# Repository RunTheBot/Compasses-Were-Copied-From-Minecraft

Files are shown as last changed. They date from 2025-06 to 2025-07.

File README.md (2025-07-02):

# Compass from Minecraft
A real compass for Minecraft, which points north in the real world.

## Features
- Points to the North in the real world.
- Looks like a minecraft compass.
- Can be used in any IRL version

## Images


<sub><sup> Got lazy with textures </sup></sub>


<sub><sup> The exploded view is upsidedown, thats why you dont see bolts in the render.</sup></sub>



## BOM

| Name | Quantity | Single Unit Price | Total Price | URL/LCSC | FALSE | Vendor (LCSC unless otheriwse indicated) | |
|---|---|---|---|---|---|---|---|
| Electronics | | | | | FALSE | | |
| C5 0603 0.1uF | 40 | | 0.45 | C49678 | FALSE | With My other two projects | |
| SK6812MINI | 40 | | $2.96 | C5149201 | FALSE | | |
| SEEED XIAO 2040 | 1 | | $3.99 | https://www.seeedstudio.com/XIAO-RP2040-v1-0-p-5026.html | FALSE | | |
| PCB - JLC | | | $9.00 | | FALSE | | |
| LCSC - Shipping and handling | | | $17.38 | | FALSE | | |
| magnometer | | | $2.07 | C2654971 | FALSE | | |
| JLC - Shipping | | | $10.38 | | FALSE | | |
| BSS138 (Level Shifter) | 1 | | 0.45 | C82045 | FALSE | With My other two projects | |
| 0603 10K | 3 | | 0.11 | C98220 | FALSE | With My other two projects | |
| seeedstudio shipping | | | $12.00 | | FALSE | | |
| | | | | | FALSE | | |
| | | | | | FALSE | | |
| | | | | | FALSE | | |
| | | | | | FALSE | | |
| | | | | | FALSE | | |
| | | | | | FALSE | | |
| | | | | | FALSE | With My other two projects | |
| | | | | | FALSE | | |
| | | | | | FALSE | | |
| | | | | | FALSE | | |
| | | | | | FALSE | | |
| | | | | | FALSE | | |
| | | | | | FALSE | | |
| | | | | | FALSE | | |
| | | | | | FALSE | | |
| | | | | | | | |
| | | | | | | | |
| | | | | | | | |
| | | | | | | | |
| | | | | | | | |
| | | | | | | | |
| | | | | | | | |
| | | | | | | | |
| | | | | | | | |
| | | | | | | | |
| | | | | CAD | | | |
| | | | $57.78 | USD | | | |
| | | | $57.78 | Total - USD | | | |

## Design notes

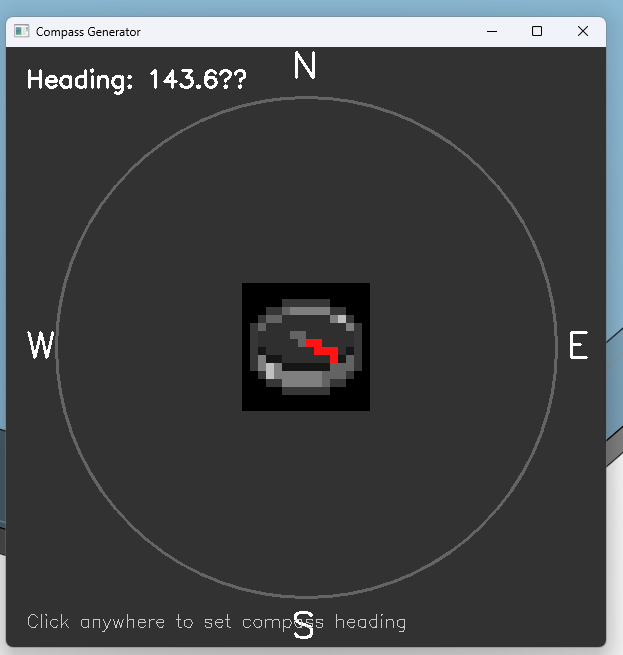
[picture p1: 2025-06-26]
image.png

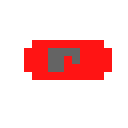
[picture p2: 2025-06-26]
generator/compassno.png

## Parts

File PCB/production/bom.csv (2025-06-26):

Designator | Footprint | Quantity | Value | LCSC Part #
C1, C10, C11, C12, C13, C14, C15, C16, C17, C18, C19, C2, C20, C21, C22, C23, C24, C25, C26, C27, C28, C29, C3, C30, C31, C32, C33, C34, C35, C36, C37, C38, C39, C4, C40, C5, C6, C7, C8, C9 | 0805 | 40 | 0.1uF
D1, D10, D11, D12, D13, D14, D15, D16, D17, D18, D19, D2, D20, D21, D22, D23, D24, D25, D26, D27, D28, D29, D3, D30, D31, D32, D33, D34, D35, D36, D37, D38, D39, D4, D40, D5, D6, D7, D8, D9 | SK6812MINI-E | 40 | SK6812MINI
Q1 | SOT-23 | 1 | BSS138
R1, R2 | 0603 | 2 | 10K
U1 | XIAO-RP2040-DIP | 1 | XIAO-RP2040-DIP

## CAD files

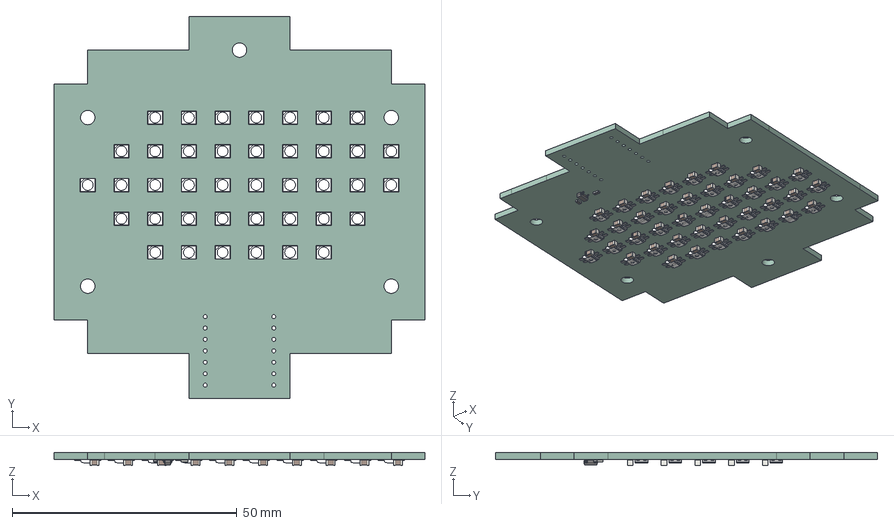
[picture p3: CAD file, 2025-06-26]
PCB/compass.step
82.5 x 85.0 x 2.84 mm
C_0805_2012Metric x 40
Pins x 40
SOT-23
R_0603_1608Metric x 2
compass_PCB

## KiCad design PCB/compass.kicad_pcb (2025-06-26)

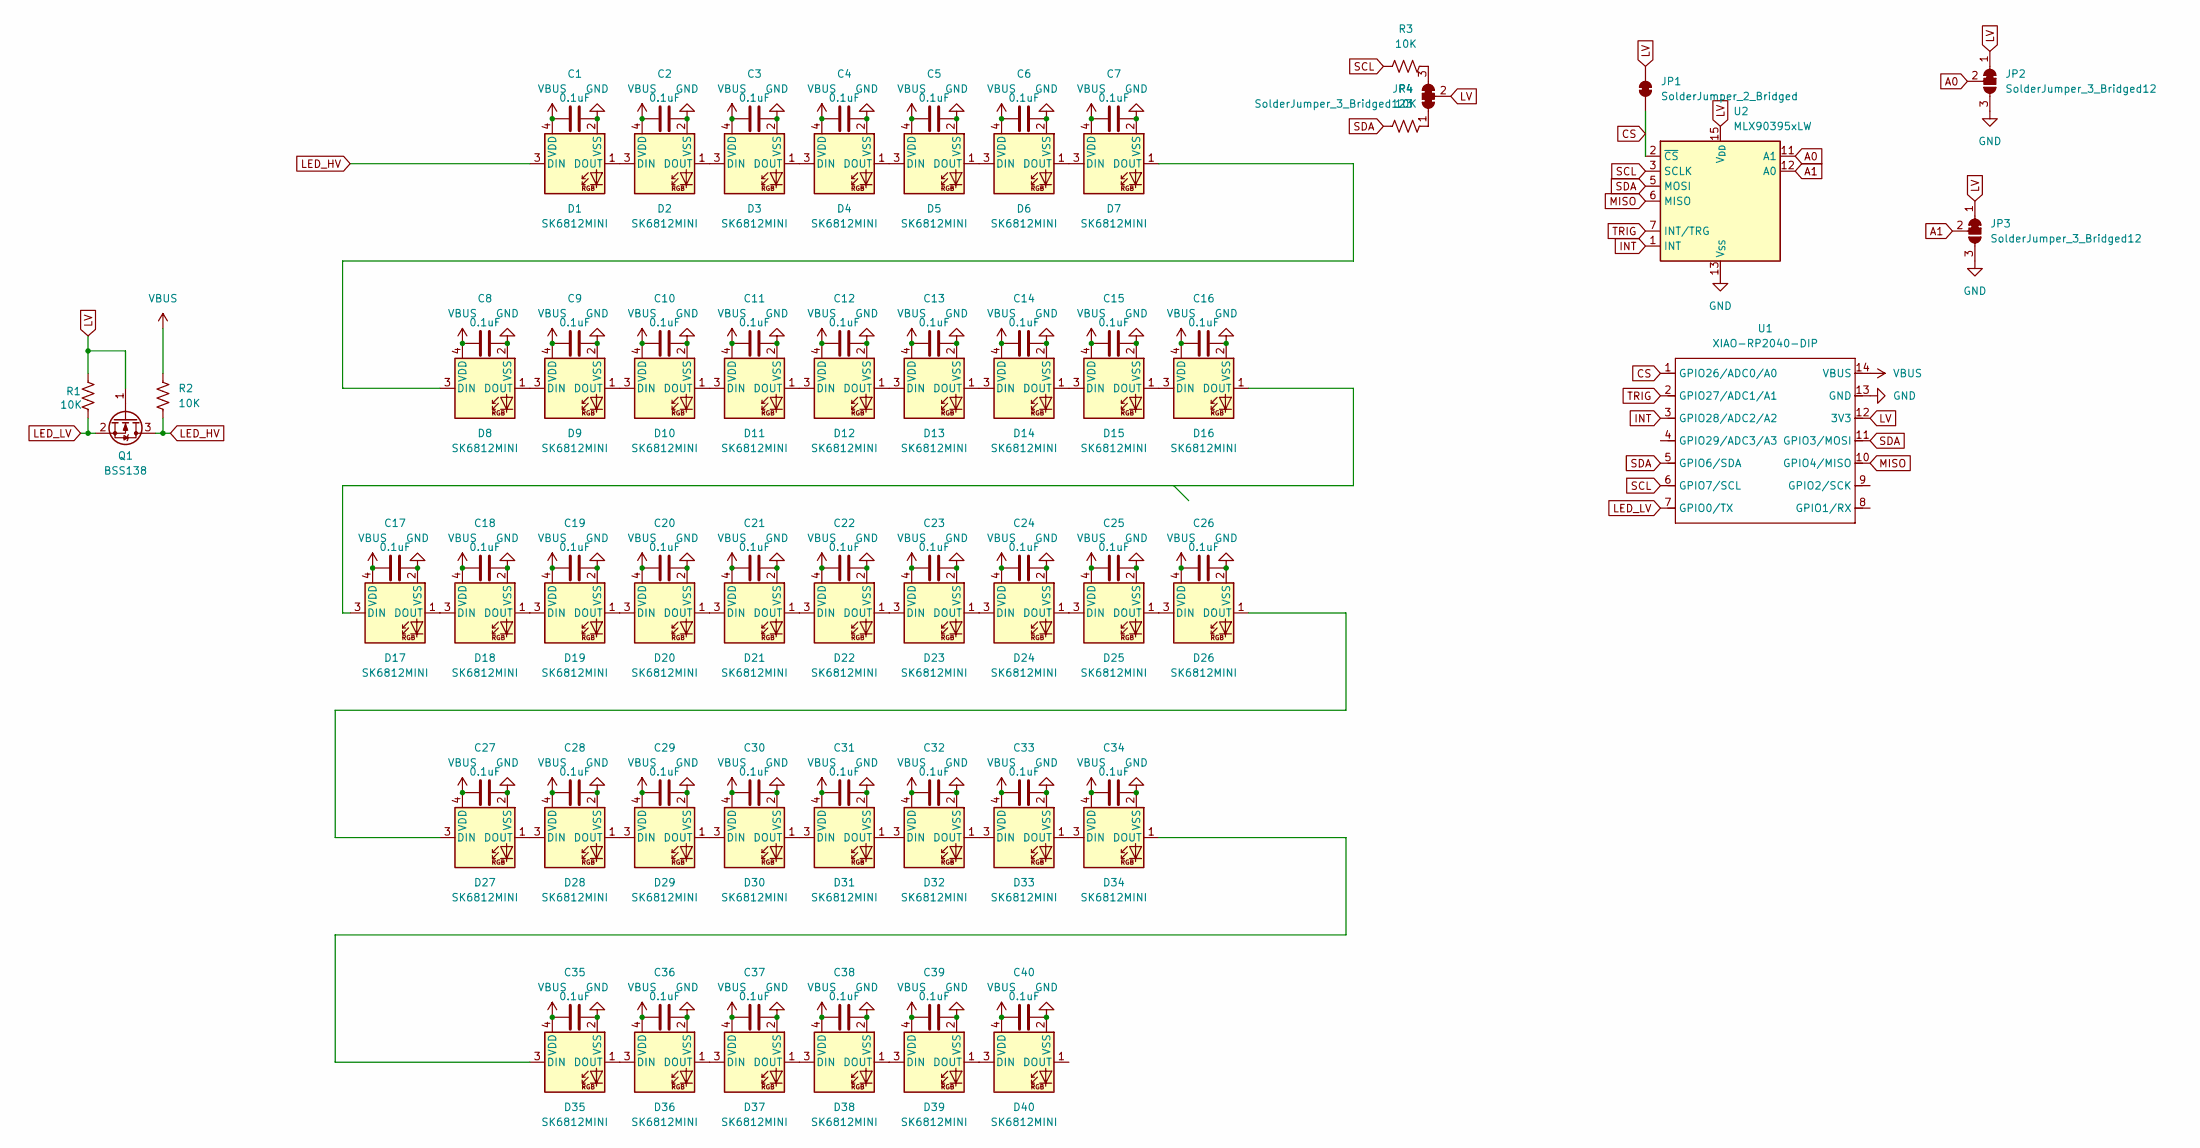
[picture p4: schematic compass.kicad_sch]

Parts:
C1, C2, C3, C4, C5, C6, C7, C8, C9, C10, C11, C12, C13, C14, C15, C16, C17, C18, C19, C20, C21, C22, C23, C24, C25, C26, C27, C28, C29, C30, C31, C32, C33, C34, C35, C36, C37, C38, C39, C40: 0.1uF; C_0805_2012Metric_Pad1.18x1.45mm_HandSolder
D1, D2, D3, D4, D5, D6, D7, D8, D9, D10, D11, D12, D13, D14, D15, D16, D17, D18, D19, D20, D21, D22, D23, D24, D25, D26, D27, D28, D29, D30, D31, D32, D33, D34, D35, D36, D37, D38, D39, D40: SK6812MINI; SK6812MINI-E
JP1: SolderJumper_2_Bridged; SolderJumper-2_P1.3mm_Bridged_RoundedPad1.0x1.5mm
JP2, JP3: SolderJumper_3_Bridged12; SolderJumper-3_P1.3mm_Bridged12_RoundedPad1.0x1.5mm
JP4: SolderJumper_3_Bridged123; SolderJumper-3_P1.3mm_Bridged123_RoundedPad1.0x1.5mm_Number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
Q1: BSS138; SOT-23
R1, R2, R3, R4: 10K; R_0603_1608Metric_Pad0.98x0.95mm_HandSolder
U1: XIAO-RP2040-DIP
U2: MLX90395xLW; QFN-16-1EP_3x3mm_P0.5mm_EP1.675x1.675mm

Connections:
A0: JP2.2 (C), U2.11 (A1)
A1: JP3.2 (C), U2.12 (A0)
CS: JP1.1 (A), U1.1 (GPIO26/ADC0/A0), U2.2 (~CS)
GND: C1.2, C2.2, C3.2, C4.2, C5.2, C6.2, C7.2, C8.2, C9.2, C10.2, C11.2, C12.2, C13.2, C14.2, C15.2, C16.2, C17.2, C18.2, C19.2, C20.2, C21.2, C22.2, C23.2, C24.2, C25.2, C26.2, C27.2, C28.2, C29.2, C30.2, C31.2, C32.2, C33.2, C34.2, C35.2, C36.2, C37.2, C38.2, C39.2, C40.2, D1.2 (VSS), D2.2 (VSS), D3.2 (VSS), D4.2 (VSS), D5.2 (VSS), D6.2 (VSS), D7.2 (VSS), D8.2 (VSS), D9.2 (VSS), D10.2 (VSS), D11.2 (VSS), D12.2 (VSS), D13.2 (VSS), D14.2 (VSS), D15.2 (VSS), D16.2 (VSS), D17.2 (VSS), D18.2 (VSS), D19.2 (VSS), D20.2 (VSS), D21.2 (VSS), D22.2 (VSS), D23.2 (VSS), D24.2 (VSS), D25.2 (VSS), D26.2 (VSS), D27.2 (VSS), D28.2 (VSS), D29.2 (VSS), D30.2 (VSS), D31.2 (VSS), D32.2 (VSS), D33.2 (VSS), D34.2 (VSS), D35.2 (VSS), D36.2 (VSS), D37.2 (VSS), D38.2 (VSS), D39.2 (VSS), D40.2 (VSS), JP2.3 (B), JP3.3 (B), U1.13 (GND), U2.4 (V_{SS}), U2.8 (V_{SS}), U2.9 (V_{SS}), U2.10 (V_{SS}), U2.13 (V_{SS}), U2.14 (V_{SS}), U2.16 (V_{SS}), U2.17 (V_{SS})
INT: U1.3 (GPIO28/ADC2/A2), U2.1 (INT)
LED_HV: D1.3 (DIN), Q1.3 (D), R2.2
LED_LV: Q1.2 (S), R1.2, U1.7 (GPIO0/TX)
LV: JP1.2 (B), JP2.1 (A), JP3.1 (A), JP4.2 (C), Q1.1 (G), R1.1, U1.12 (3V3), U2.15 (V_{DD})
MISO: U1.10 (GPIO4/MISO), U2.6 (MISO)
unnamed: D1.1 (DOUT), D2.3 (DIN)
unnamed: D2.1 (DOUT), D3.3 (DIN)
unnamed: D3.1 (DOUT), D4.3 (DIN)
unnamed: D4.1 (DOUT), D5.3 (DIN)
unnamed: D5.1 (DOUT), D6.3 (DIN)
unnamed: D6.1 (DOUT), D7.3 (DIN)
unnamed: D7.1 (DOUT), D8.3 (DIN)
unnamed: D8.1 (DOUT), D9.3 (DIN)
unnamed: D9.1 (DOUT), D10.3 (DIN)
unnamed: D10.1 (DOUT), D11.3 (DIN)
unnamed: D11.1 (DOUT), D12.3 (DIN)
unnamed: D12.1 (DOUT), D13.3 (DIN)
unnamed: D13.1 (DOUT), D14.3 (DIN)
unnamed: D14.1 (DOUT), D15.3 (DIN)
unnamed: D15.1 (DOUT), D16.3 (DIN)
unnamed: D16.1 (DOUT), D17.3 (DIN)
unnamed: D17.1 (DOUT), D18.3 (DIN)
unnamed: D18.1 (DOUT), D19.3 (DIN)
unnamed: D19.1 (DOUT), D20.3 (DIN)
unnamed: D20.1 (DOUT), D21.3 (DIN)
unnamed: D21.1 (DOUT), D22.3 (DIN)
unnamed: D22.1 (DOUT), D23.3 (DIN)
unnamed: D23.1 (DOUT), D24.3 (DIN)
unnamed: D24.1 (DOUT), D25.3 (DIN)
unnamed: D25.1 (DOUT), D26.3 (DIN)
unnamed: D26.1 (DOUT), D27.3 (DIN)
unnamed: D27.1 (DOUT), D28.3 (DIN)
unnamed: D28.1 (DOUT), D29.3 (DIN)
unnamed: D29.1 (DOUT), D30.3 (DIN)
unnamed: D30.1 (DOUT), D31.3 (DIN)
unnamed: D31.1 (DOUT), D32.3 (DIN)
unnamed: D32.1 (DOUT), D33.3 (DIN)
unnamed: D33.1 (DOUT), D34.3 (DIN)
unnamed: D34.1 (DOUT), D35.3 (DIN)
unnamed: D35.1 (DOUT), D36.3 (DIN)
unnamed: D36.1 (DOUT), D37.3 (DIN)
unnamed: D37.1 (DOUT), D38.3 (DIN)
unnamed: D38.1 (DOUT), D39.3 (DIN)
unnamed: D39.1 (DOUT), D40.3 (DIN)
unnamed: JP4.1 (A), R4.2
unnamed: JP4.3 (B), R3.2
SCL: R3.1, U1.6 (GPIO7/SCL), U2.3 (SCLK)
SDA: R4.1, U1.5 (GPIO6/SDA), U1.11 (GPIO3/MOSI), U2.5 (MOSI)
TRIG: U1.2 (GPIO27/ADC1/A1), U2.7 (INT/TRG)
VBUS: C1.1, C2.1, C3.1, C4.1, C5.1, C6.1, C7.1, C8.1, C9.1, C10.1, C11.1, C12.1, C13.1, C14.1, C15.1, C16.1, C17.1, C18.1, C19.1, C20.1, C21.1, C22.1, C23.1, C24.1, C25.1, C26.1, C27.1, C28.1, C29.1, C30.1, C31.1, C32.1, C33.1, C34.1, C35.1, C36.1, C37.1, C38.1, C39.1, C40.1, D1.4 (VDD), D2.4 (VDD), D3.4 (VDD), D4.4 (VDD), D5.4 (VDD), D6.4 (VDD), D7.4 (VDD), D8.4 (VDD), D9.4 (VDD), D10.4 (VDD), D11.4 (VDD), D12.4 (VDD), D13.4 (VDD), D14.4 (VDD), D15.4 (VDD), D16.4 (VDD), D17.4 (VDD), D18.4 (VDD), D19.4 (VDD), D20.4 (VDD), D21.4 (VDD), D22.4 (VDD), D23.4 (VDD), D24.4 (VDD), D25.4 (VDD), D26.4 (VDD), D27.4 (VDD), D28.4 (VDD), D29.4 (VDD), D30.4 (VDD), D31.4 (VDD), D32.4 (VDD), D33.4 (VDD), D34.4 (VDD), D35.4 (VDD), D36.4 (VDD), D37.4 (VDD), D38.4 (VDD), D39.4 (VDD), D40.4 (VDD), R2.1, U1.14 (VBUS)

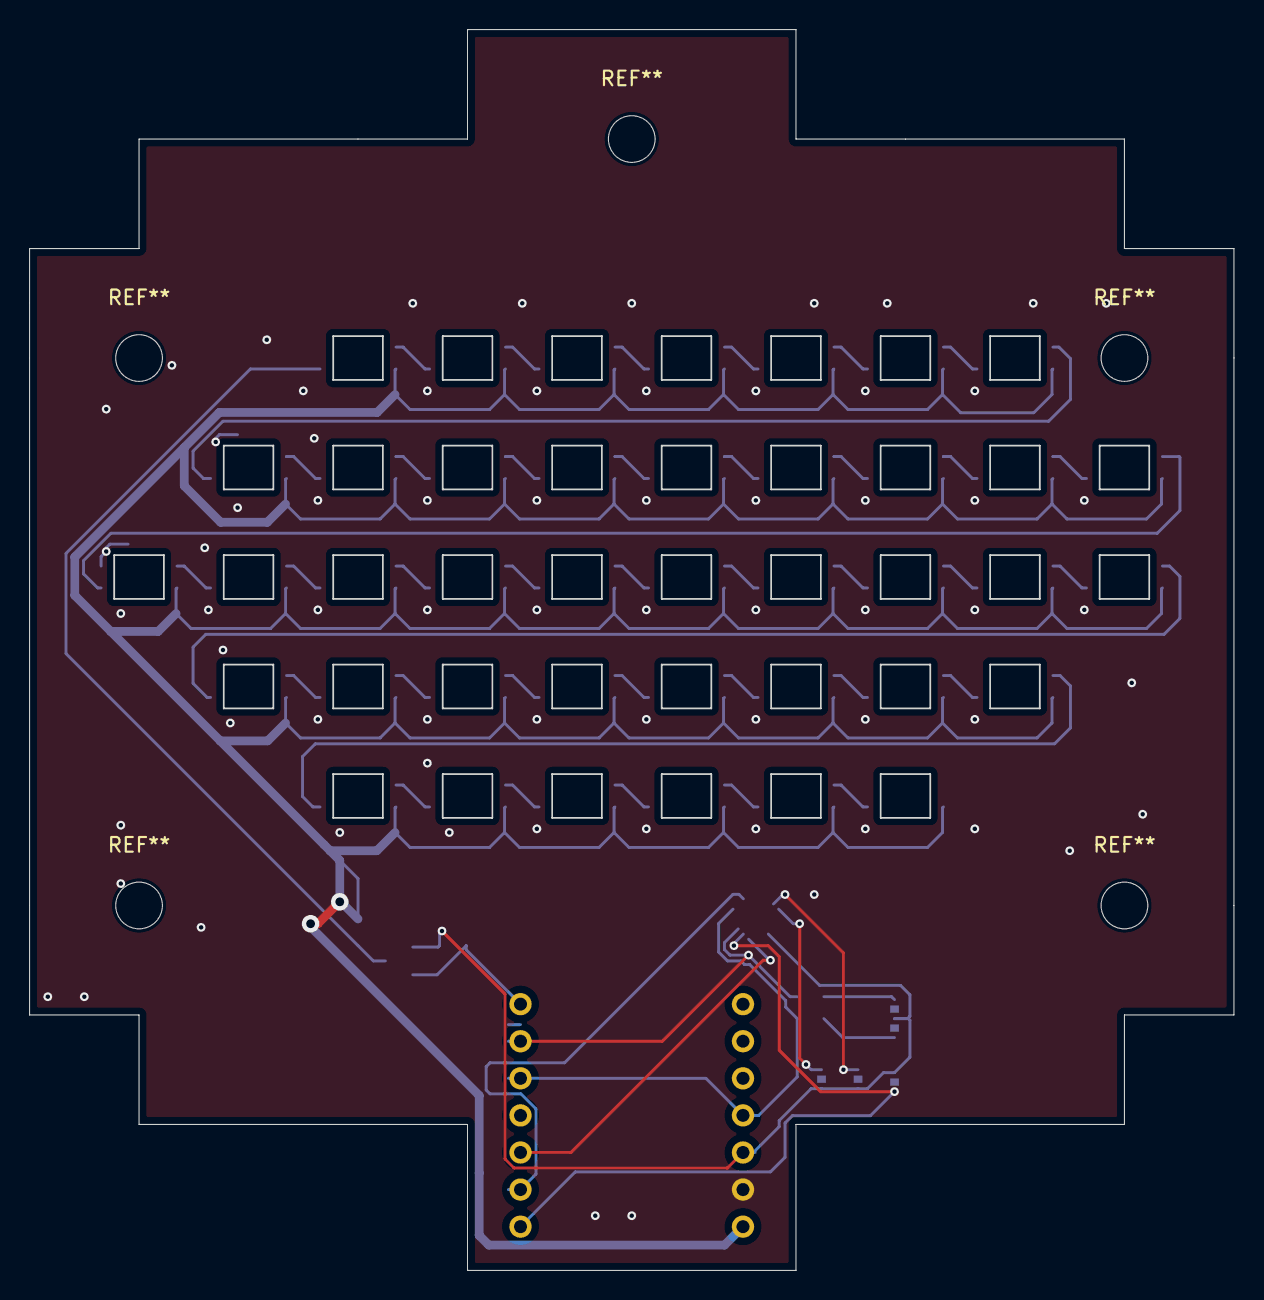
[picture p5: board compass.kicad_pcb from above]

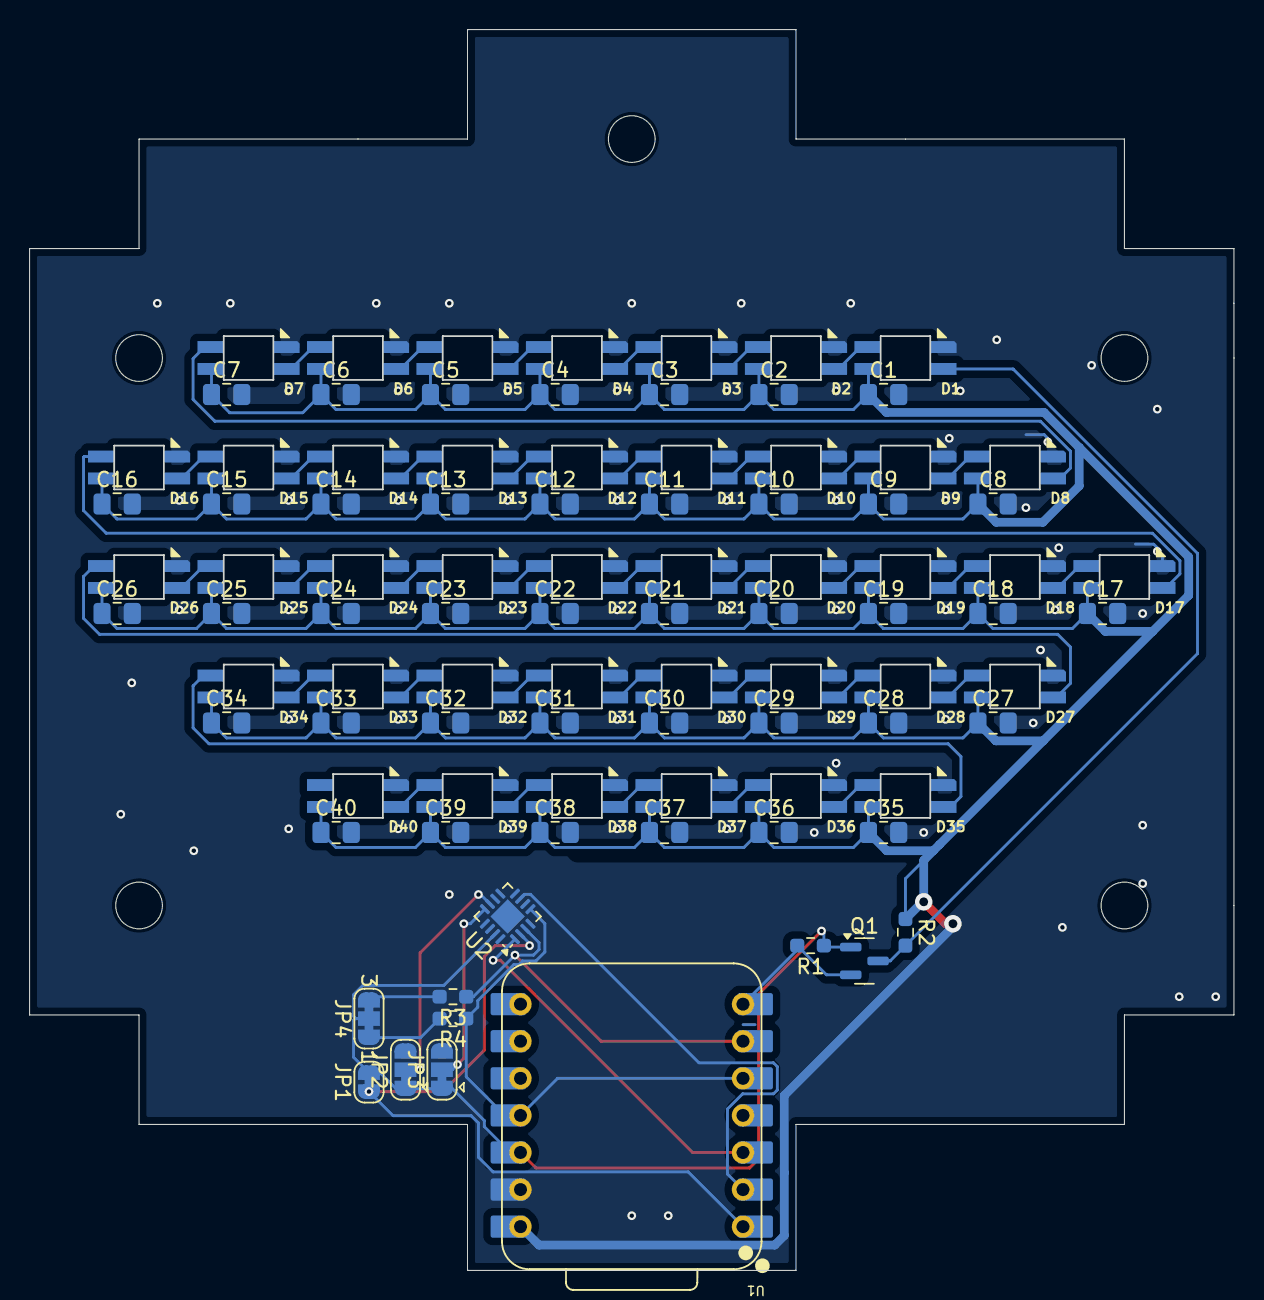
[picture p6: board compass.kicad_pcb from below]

Board: 2 copper layers, 82.5 x 85.0 mm, 91 parts (91 on the bottom side), 54 nets.

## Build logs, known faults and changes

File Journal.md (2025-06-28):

---
title: "Compasses-Were-Copied-From-Minecraft"
author: "RunTheBot"
description: "Compass from minecraft"
created_at: "2025-06-24"
---

Hours: 12

# 6/25/2025

Made the entire thing.

I started with a digital generator that I made in Python. It was a simple program that generated the spirts for the compass. This was taken from the Minecraft wiki.



then I put these images into a photo editor to see what pixels I needed to be LEDs.

using blending options I can see what pixels I needed to be LEDs.



I then stated the schmatic. 



I choose the XIAO RP2040 as the microcontroller because it was small and cheap.

I then made the PCB. I traced out the compass then I used grid to align the LEDs.



I then made a case in CAD. 



BOM
